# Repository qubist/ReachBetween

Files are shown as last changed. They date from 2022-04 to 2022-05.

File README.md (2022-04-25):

RB02
====

Simple, cheap, hackable, DIY, open-source USB-C input switcher

Background
----------

I couldn't find a good USB-C switch with two outputs that wasn't hundreds of
dollars, so I built my own. (Also I wanted an excuse to learn PCB design, and I
was able to secure a few free sample rotary switches from an electronics
company.) The result is the RB02, a two-output one-input bidirectional USB-C
input switcher smaller than a credit card.

The RB02 has three USB-C ports, one on the front and two on the back. A knob on top has three positions, left, right, and center. In the left or right position, the device connects the USB port on the front to the left or right USB port on the back. 

It's resonable to make as a weekend project as long as you've got a fine
soldering iron for the few surface-mount pads.

Gallery
-------

FIXME

Bill of Materials
-----------------

| Item | Manufacturer  | Part number | Quantity | Unit price | Total price |
|---|---|---|---|---|---|
| Rotary switch | NKK Switches  | MRA-403-A | 1 | $24.17 | $24.17 |
| 18-8 Stainless Steel Socket Head Screw, M2 x 25mm | McMaster Carr | 91292A032 | 4 | | $6.21 (pack of 10) |
| 18-8 Stainless Steel Hex Nut, M2 | McMaster Carr | 91828A111 | 4 | | $6.14 (pack of 100) |
| 1/4" Adhesive-Back Bumper | McMaster Carr | 8215K219 | 3 | $2.06 | $6.18 |
| Custom Printed Circuit Board | Aisler | | 1 | $7.04 | $21.10 (minimum order 3) |
| Standard LED | | | 1 | | |
| Standard resistor | | | 1 | | |
| USB-C receptacle | JAE | DX07S016JA1R1500 | 3 | $1.67 | $5.01 |
| | | | | | **~$70** |

Assembly
--------

### PCB assembly

FIXME

- Different resistor values result in different brightnesses of the LED. 420Ω
  is around full brightness. I like mine pretty dim so I chose FIXMEΩ
- To disable the LED entirely just remove the resistor. Or don't install the
  LED at all. One could easily redesign the case to remove the LED hole.

### Case assembly

FIXME

- Clip off leads sticking through PCB to 2mm or less
- MR-A403 should be installed in this configuration from top to bottom:
  * Knob
  * Hex Face Nut
  * Case
  * Locking Ring (with nub pointing up into hole in case)
  * Factory Assembled switch
  Refer to page 4 of the [datasheet](for definitions and details).

License
-------

[GNU General Public License v3.0](LICENSE)

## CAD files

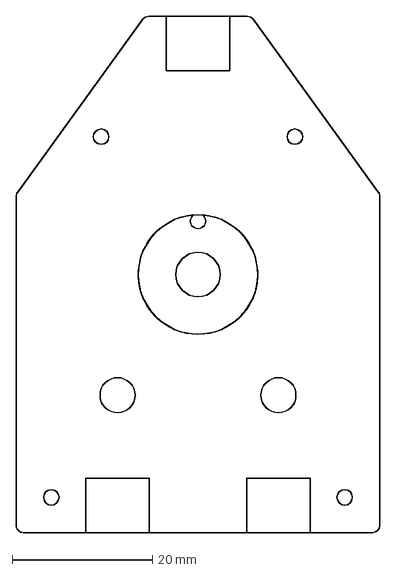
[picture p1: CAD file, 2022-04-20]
Board-from-case.dxf
51.8 x 73.5 mm

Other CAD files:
case/ReachBetween v34.f3d

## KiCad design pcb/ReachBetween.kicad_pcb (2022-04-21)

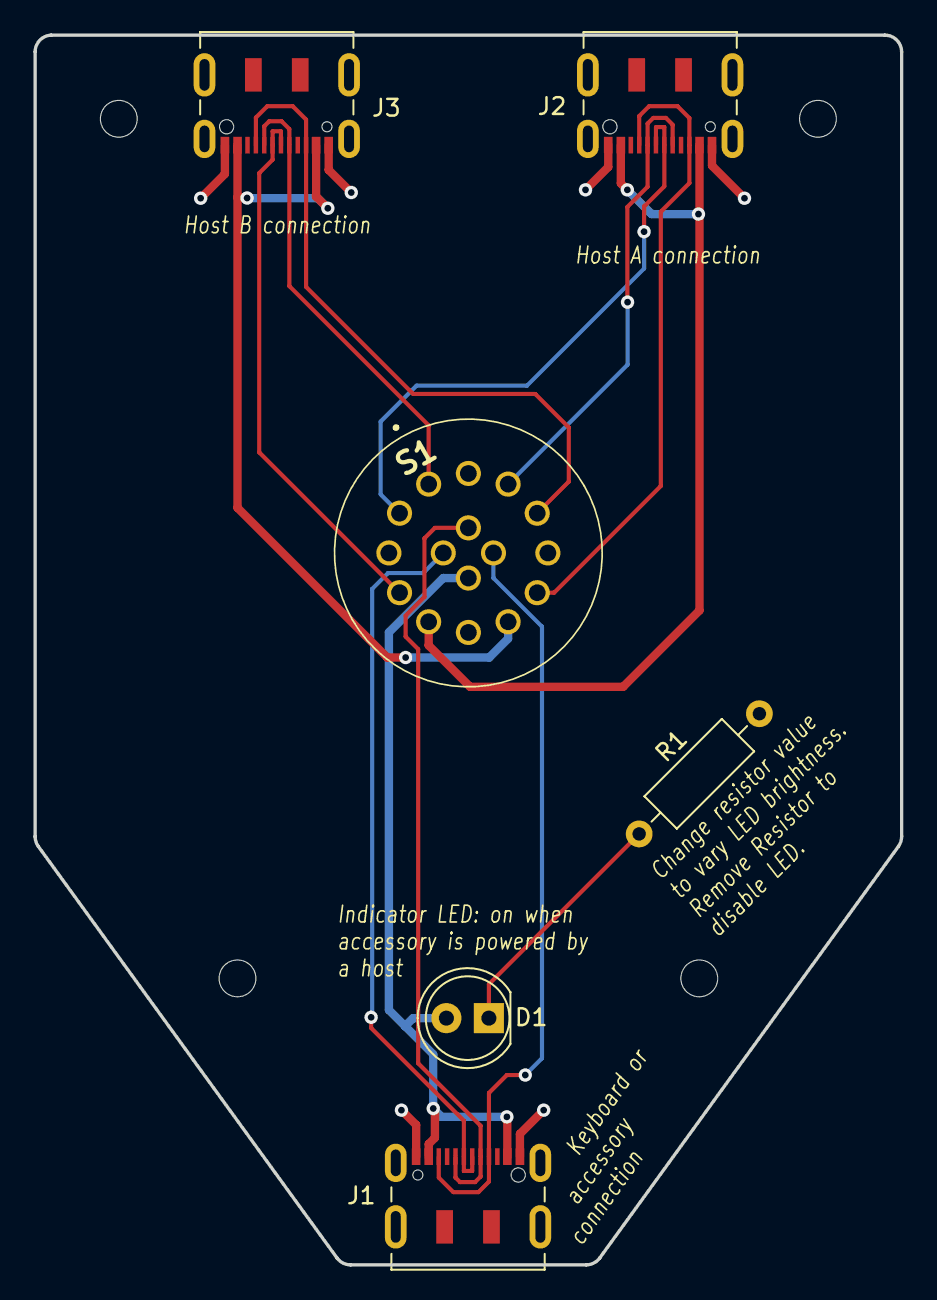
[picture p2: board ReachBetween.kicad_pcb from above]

Board: 2 copper layers, 51.8 x 73.5 mm, 6 parts (0 on the bottom side), 14 nets.

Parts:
D1: LED; LED_D5.0mm_Clear
J1: IN; USB_C_Receptacle_JAE_DX07S016JA1R1500_AislerCompatible
J2: Out A; USB_C_Receptacle_JAE_DX07S016JA1R1500_AislerCompatible
J3: Out B; USB_C_Receptacle_JAE_DX07S016JA1R1500_AislerCompatible
R1: 5.1K; R_Axial_DIN0207_L6.3mm_D2.5mm_P10.16mm_Horizontal
S1: MRA403; Rotary_Switch_NKK_MRA403-BB_2-3

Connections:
/CC A: J2.A5 (CC1), J2.B5 (CC2), S1.6
/CC B: J3.A5 (CC1), J3.B5 (CC2), S1.4
/CC in: J1.A5 (CC1), J1.B5 (CC2), S1.D1 (COM_3)
/Common Ground: J1.A1 (GND), J1.A12 (GND), J1.B1 (GND), J1.B12 (GND), J1.S1 (SHIELD), J2.A1 (GND), J2.A12 (GND), J2.B1 (GND), J2.B12 (GND), J2.S1 (SHIELD), J3.A1 (GND), J3.A12 (GND), J3.B1 (GND), J3.B12 (GND), J3.S1 (SHIELD), R1.2
/D+ A: J2.A6 (D+), J2.B6 (D+), S1.12
/D+ B: J3.A6 (D+), J3.B6 (D+), S1.10
/D+ in: J1.A6 (D+), J1.B6 (D+), S1.C1 (COM_3)
/D- A: J2.A7 (D-), J2.B7 (D-), S1.3
/D- B: J3.A7 (D-), J3.B7 (D-), S1.1
/D- in: J1.A7 (D-), J1.B7 (D-), S1.B1 (COM_2)
/VBUS A: J2.A4 (VBUS), J2.A9 (VBUS), J2.B4 (VBUS), J2.B9 (VBUS), S1.9
/VBUS B: J3.A4 (VBUS), J3.A9 (VBUS), J3.B4 (VBUS), J3.B9 (VBUS), S1.7
/VBUS in: D1.2 (A), J1.A4 (VBUS), J1.A9 (VBUS), J1.B4 (VBUS), J1.B9 (VBUS), S1.A1 (COM_1)
unnamed: D1.1 (K), R1.1

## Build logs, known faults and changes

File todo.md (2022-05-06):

TODO
----

* Post question on SE about circuit
* Test with more consistent USB-C cables
* give up on CC and ground them with 5.1kΩ resistors?
* Stop sharing ground?

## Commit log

2022-04-20 Finish board
    [Board-from-case.dxf, ReachBetween.kicad_pcb, ReachBetween.kicad_sch]
2022-04-21 Fix warnings (unconnected tracks)!
    [ReachBetween.kicad_pcb]
2022-04-21 Round tracks
    [ReachBetween-rounded.kicad_pcb]
2022-04-21 Teardrop tracks
    [ReachBetween-rounded.kicad_pcb]
2022-04-21 Update version number
    [ReachBetween-rounded.kicad_pcb]
2022-04-21 Update version number correspondingly on source PCB
    [ReachBetween.kicad_pcb]
2022-04-21 Round silkscreen lines on back
    [ReachBetween-rounded.kicad_pcb, ReachBetween.kicad_pcb]
2022-04-25 Add case design files
    [RB02 Bottom Case v21.stl, RB02 Top case v21.stl, ReachBetween v21.f3d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]
2022-05-06 Update case after seeing boards in person
    [RB02 Bottom Case v21.stl, RB02 Top case v21.stl, ReachBetween v21.f3d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]

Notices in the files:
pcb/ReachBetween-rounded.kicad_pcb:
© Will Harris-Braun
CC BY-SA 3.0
